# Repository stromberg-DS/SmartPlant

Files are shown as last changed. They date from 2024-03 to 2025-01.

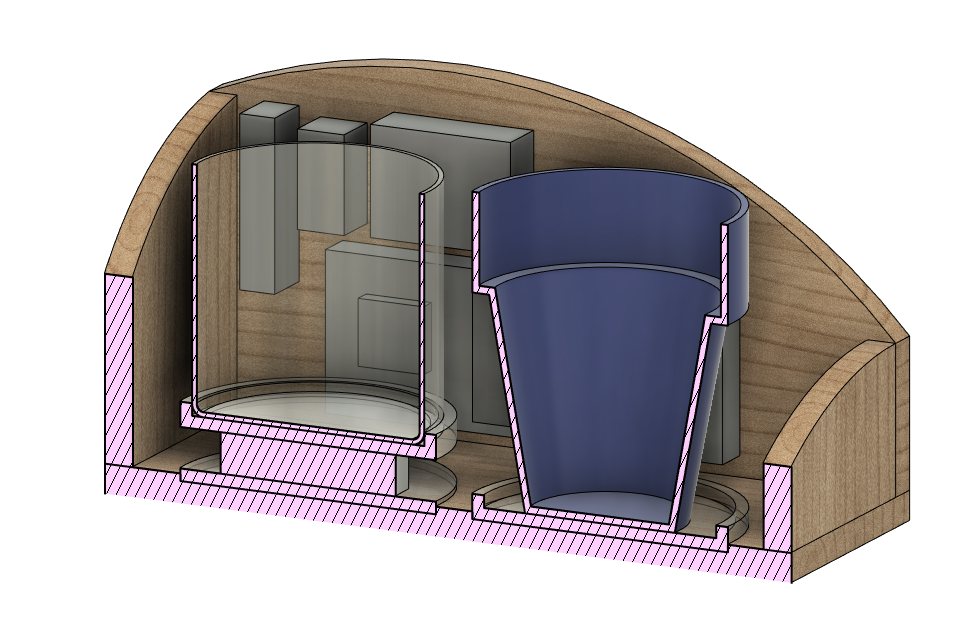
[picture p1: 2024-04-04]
Images/Slice.png

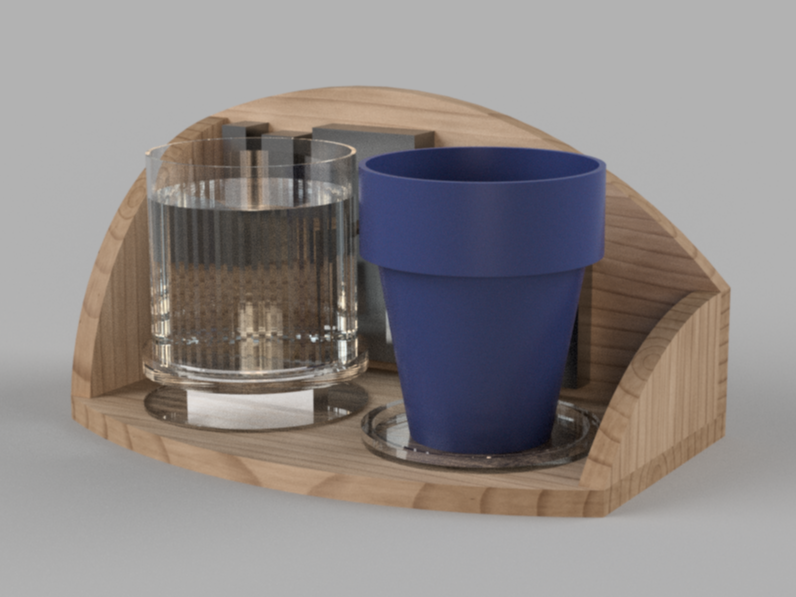
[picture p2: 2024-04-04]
Images/SmartPlant_Render1.png

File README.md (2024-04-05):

# SmartPlant

This is a smart plant system that monitors air quality, temperature, humidity, and more while keeping a plant watered and happy. All of the sensor data is displayed on an OLED in addition to publishing to an Adafruit.io dashboard.

The project runs on a Particle Photon 2 which was programmed in C++ in VS Code. Install the Particle Workbench to VS Code to edit any code here.

## Directory

**PlantCareAndMonitoringSystem** - This is the main project folder. The final code, wiring diagrams, and other important info is in this folder.

**Cut_Files** - Any files for laser cutting or cutting on a CNC router will be in here. 

**Images** - Pictures of my plant care and monitoring system.

**SP_#####Tests** - These were initial tests to dial in the sensors and code before combining them into the final product. Move along, nothing to see here.

More information and a list of parts can be found at [my Hackster.io writeup.](https://www.hackster.io/blotlat/plant-care-system-857033)

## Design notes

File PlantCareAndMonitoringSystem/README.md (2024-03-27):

# PlantCareAndMonitoringSystem

This firmware project was created using [Particle Developer Tools](https://www.particle.io/developer-tools/) and is compatible with all [Particle Devices](https://www.particle.io/devices/).

Feel free to replace this README.md file with your own content, or keep it for reference.

## Table of Contents
- [Introduction](#introduction)
- [Prerequisites To Use This Template](#prerequisites-to-use-this-repository)
- [Getting Started](#getting-started)
- [Particle Firmware At A Glance](#particle-firmware-at-a-glance)
  - [Logging](#logging)
  - [Setup and Loop](#setup-and-loop)
  - [Delays and Timing](#delays-and-timing)
  - [Testing and Debugging](#testing-and-debugging)
  - [GitHub Actions (CI/CD)](#github-actions-cicd)
  - [OTA](#ota)
- [Support and Feedback](#support-and-feedback)
- [Version](#version)

## Introduction

For an in-depth understanding of this project template, please refer to our [documentation](https://docs.particle.io/firmware/best-practices/firmware-template/).

## Prerequisites To Use This Repository

To use this software/firmware on a device, you'll need:

- A [Particle Device](https://www.particle.io/devices/).
- Windows/Mac/Linux for building the software and flashing it to a device.
- [Particle Development Tools](https://docs.particle.io/getting-started/developer-tools/developer-tools/) installed and set up on your computer.
- Optionally, a nice cup of tea (and perhaps a biscuit).

## Getting Started

1. While not essential, we recommend running the [device setup process](https://setup.particle.io/) on your Particle device first. This ensures your device's firmware is up-to-date and you have a solid baseline to start from.

2. If you haven't already, open this project in Visual Studio Code (File -> Open Folder). Then [compile and flash](https://docs.particle.io/getting-started/developer-tools/workbench/#cloud-build-and-flash) your device. Ensure your device's USB port is connected to your computer.

3. Verify the device's operation by monitoring its logging output:
    - In Visual Studio Code with the Particle Plugin, open the [command palette](https://docs.particle.io/getting-started/developer-tools/workbench/#particle-commands) and choose "Particle: Serial Monitor".
    - Or, using the Particle CLI, execute:
    ```
    particle serial monitor --follow
    ```

4. Uncomment the code at the bottom of the cpp file in your src directory to publish to the Particle Cloud! Login to console.particle.io to view your devices events in real time.

5. Customize this project! For firmware details, see [Particle firmware](https://docs.particle.io/reference/device-os/api/introduction/getting-started/). For information on the project's directory structure, visit [this link](https://docs.particle.io/firmware/best-practices/firmware-template/#project-overview).

## Particle Firmware At A Glance

### Logging

The firmware includes a [logging library](https://docs.particle.io/reference/device-os/api/logging/logger-class/). You can display messages at different levels and filter them:

```
Log.trace("This is trace message");
Log.info("This is info message");
Log.warn("This is warn message");
Log.error("This is error message");
```

### Setup and Loop

Particle projects originate from the Wiring/Processing framework, which is based on C++. Typically, one-time setup functions are placed in `setup()`, and the main application runs from the `loop()` function.

For advanced scenarios, explore our [threading support](https://docs.particle.io/firmware/software-design/threading-explainer/).

### Delays and Timing

By default, the setup() and loop() functions are blocking whilst they run, meaning that if you put in a delay, your entire application will wait for that delay to finish before anything else can run. 

For techniques that allow you to run multiple tasks in parallel without creating threads, checkout the code example [here](https://docs.particle.io/firmware/best-practices/firmware-template/).

(Note: Although using `delay()` isn't recommended for best practices, it's acceptable for testing.)

### Testing and Debugging

For firmware testing and debugging guidance, check [this documentation](https://docs.particle.io/troubleshooting/guides/build-tools-troubleshooting/debugging-firmware-builds/).

### GitHub Actions (CI/CD)

This project provides a YAML file for GitHub, automating firmware compilation whenever changes are pushed. More details on [Particle GitHub Actions](https://docs.particle.io/firmware/best-practices/github-actions/) are available.

### OTA

To learn how to utilize Particle's OTA service for device updates, consult [this documentation](https://docs.particle.io/getting-started/cloud/ota-updates/).

Test OTA with the 'Particle: Cloud Flash' command in Visual Studio Code or the CLI command 'particle flash'!

This firmware supports binary assets in OTA packages, allowing the inclusion of audio, images, configurations, and external microcontroller firmware. More details are [here](https://docs.particle.io/reference/device-os/api/asset-ota/asset-ota/).

## Support and Feedback

For support or feedback on this template or any Particle products, please join our [community](https://community.particle.io)!

## Version

Template version 1.0.2

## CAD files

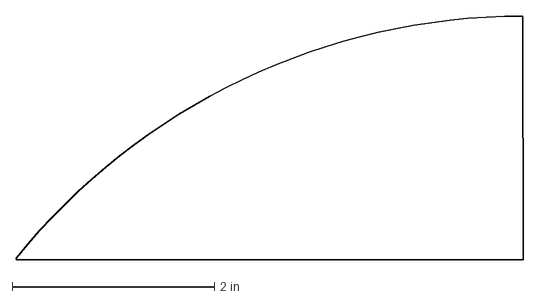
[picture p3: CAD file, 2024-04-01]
Cut_Files/RightWallCut.dxf
5.01 x 2.41 in

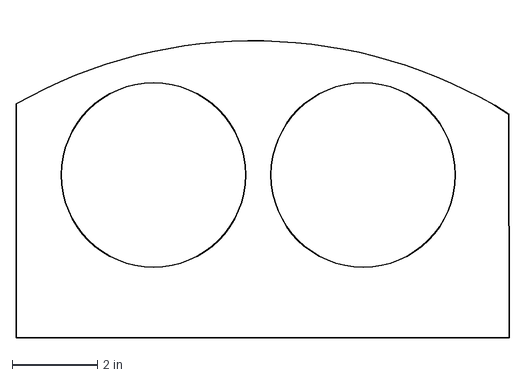
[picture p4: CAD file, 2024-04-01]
Cut_Files/ButtomCut.dxf
11.6 x 7.54 in

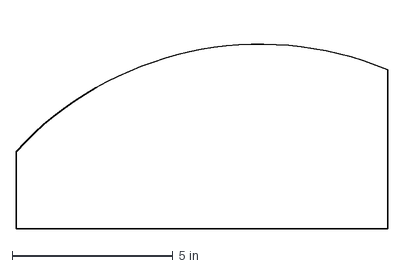
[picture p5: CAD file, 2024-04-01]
Cut_Files/BackWallCut.dxf
11.6 x 6.63 in

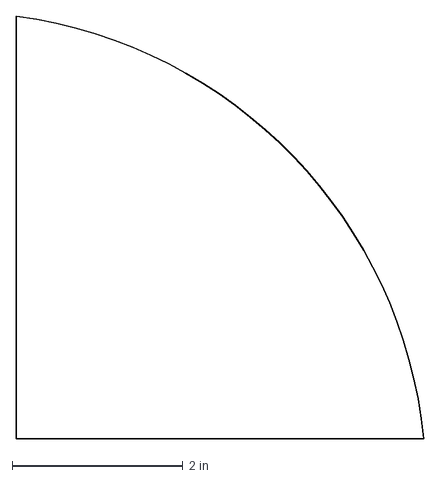
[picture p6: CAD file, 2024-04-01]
Cut_Files/LeftWallCut.dxf
4.77 x 4.95 in

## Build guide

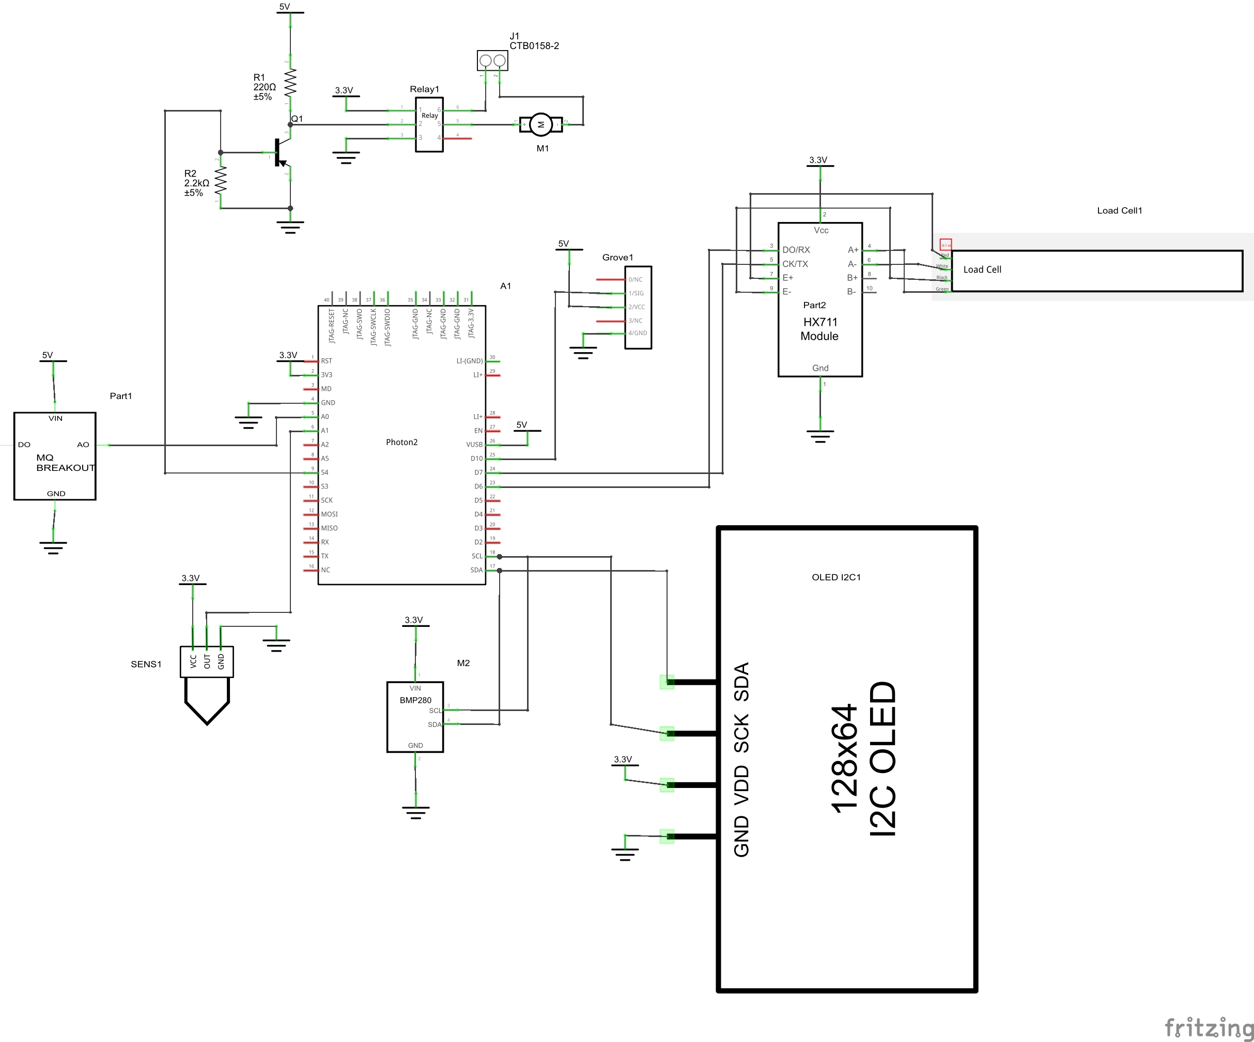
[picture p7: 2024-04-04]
PlantCareAndMonitoringSystem/SmartPlantWiring_schem.jpg

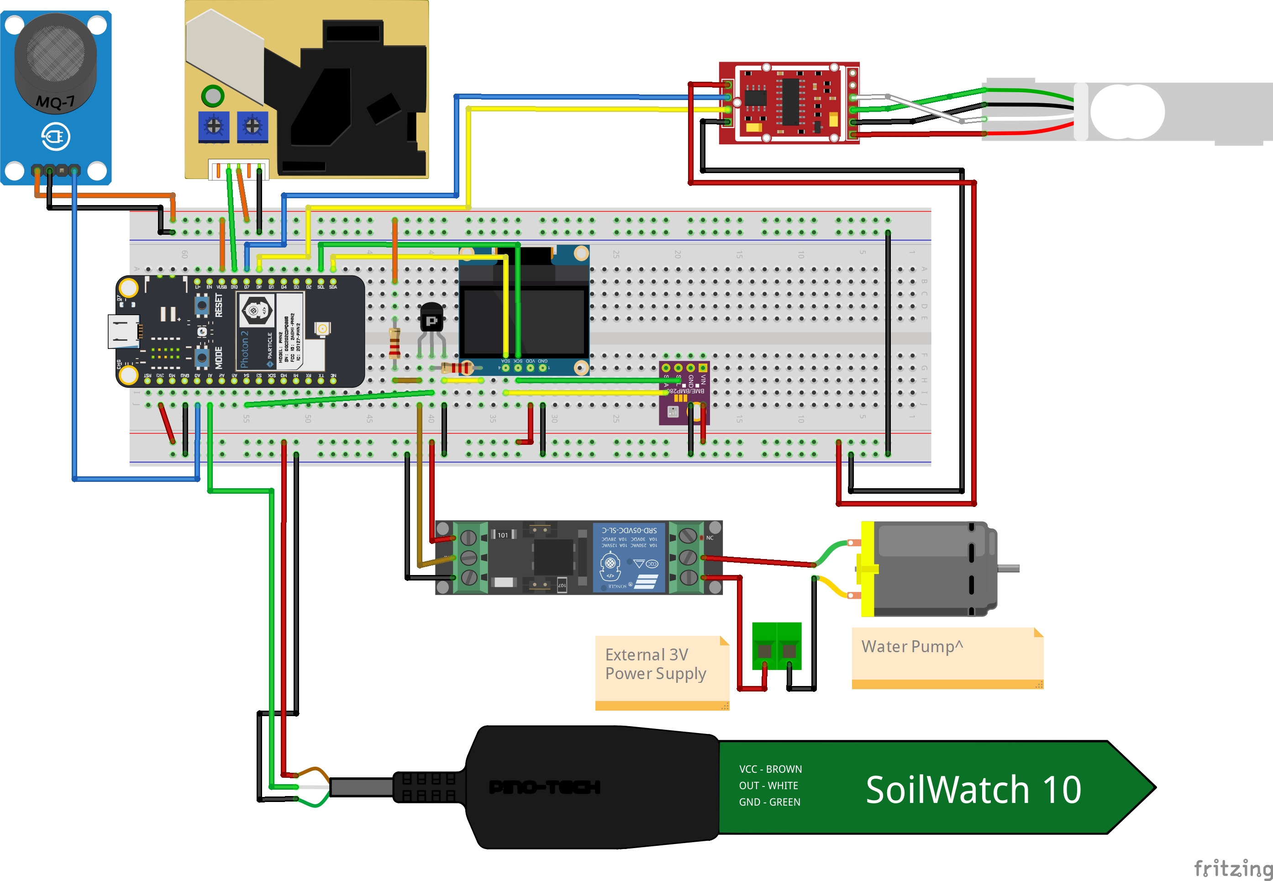
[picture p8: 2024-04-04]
PlantCareAndMonitoringSystem/SmartPlantWiring_bb.jpg

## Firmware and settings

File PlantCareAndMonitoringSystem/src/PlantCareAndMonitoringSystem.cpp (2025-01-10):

/* 
 * Plant Care & Monitoring System
 * Author: Daniel Stromberg
 * Date: 3/26/2024
*/

#include "Particle.h"
#include "math.h"
#include <Air_Quality_Sensor.h>
#include <Adafruit_MQTT/Adafruit_MQTT_SPARK.h>
#include <Adafruit_MQTT/Adafruit_MQTT.h>
#include "credentials.h"
#include <Adafruit_BME280.h>
#include <Adafruit_GFX.h>
#include <Adafruit_SSD1306.h>
#include "HX711.h"
#include "math.h"

//Sensor 
const int DUST_PIN = 10;
const int AIR_QUALITY_PIN = A0;
const int SAMPLE_TIME_MS = 30000;
const int BME_ADDRESS = 0x76;
const int SOIL_PIN = A1;

//Display 
const int OLED_RESET =-1;
const int OLED_ADDRESS = 0x3C;
const int DEGREE_SYMBOL = 0xF8;

//Pump 
const int PUMP_PIN = D19;
const int PUMP_ON_TIME = 500;
const int PUMP_TIMEOUT = 1800000;       //30 minutes
int lastPumpTime = -9999;
bool isPumpOn = false;
bool isWebButtonPressed;
bool isManualPumping = false;

//Moisture 
const int SENSOR_IN_WATER = 1744;       //when sensor is in pure pureWater
const int SENSOR_IN_AIR = 3485;         //sensor value in air
const int SENSOR_IN_WET_SOIL = 1770;    //sensor value in VERY wet soil
const int SENSOR_IN_DRY_SOIL = 3500;    //sensor value in dry soil
const int TIME_TO_WATER_PERCENT = 40;

//Scale 
const float CAL_FACTOR = -478.79;
const int SAMPLES = 10;
const float EMPTY_WEIGHT = 130.0;   //No water, pump and cup only
const float LOW_WEIGHT = 230.0;     //Lowest water level before pump stops working
const float FULL_WEIGHT = 625.0;    //Full of water. 

//Timing
int currentMillis;
int lastDisplayTime = 0;

//Dust/VOC Sensors
const int SAMPLE_TIME = 30000;
int duration;
int totalLowTime = 0;
int lowPulseOccupancy = 0;
int lastLowTime = 0;
int lastSampleTime;
float ratio = 0;
float concentration = 0;
String warningText;

//BME
bool status;


TCPClient TheClient;
Adafruit_MQTT_SPARK mqtt(&TheClient, AIO_SERVER, AIO_SERVERPORT, AIO_USERNAME, AIO_KEY);
Adafruit_MQTT_Publish dustPub = Adafruit_MQTT_Publish(&mqtt, AIO_USERNAME "/feeds/plantinfo.dustsensor");
Adafruit_MQTT_Publish airQualityText = Adafruit_MQTT_Publish(&mqtt, AIO_USERNAME "/feeds/airqualitywarningtext");
Adafruit_MQTT_Publish tempPub = Adafruit_MQTT_Publish(&mqtt, AIO_USERNAME "/feeds/temperature");
Adafruit_MQTT_Publish humidityPub = Adafruit_MQTT_Publish(&mqtt, AIO_USERNAME "/feeds/plantinfo.humidity");
Adafruit_MQTT_Publish scalePub = Adafruit_MQTT_Publish(&mqtt, AIO_USERNAME "/feeds/smartscale");
Adafruit_MQTT_Publish moisturePub = Adafruit_MQTT_Publish(&mqtt, AIO_USERNAME "/feeds/plantinfo.soilmoisture");
Adafruit_MQTT_Subscribe waterButtonFeed = Adafruit_MQTT_Subscribe(&mqtt, AIO_USERNAME "/feeds/buttononoff");

AirQualitySensor sensor(AIR_QUALITY_PIN);
Adafruit_SSD1306 display(OLED_RESET);
Adafruit_BME280 bme;
HX711 myScale(D6, D7);

String DateTime, TimeOnly, Day, MonthDate, Year;

SYSTEM_MODE(AUTOMATIC);
SYSTEM_THREAD(ENABLED);

//functions
void updateDisplays(String _airQuality, float _tempF, float _humidity, float _moisturePercent);
float tempCtoF(float c);
void MQTT_connect();
bool MQTT_ping();
void getConc();
float mapFloat(float inVal, float minIn, float maxIn, float minOut, float maxOut);


void setup() {
    Serial.begin(9600);
    waitFor(Serial.isConnected, 10000);
    new Thread("concThread", getConc); 

    pinMode(PUMP_PIN, OUTPUT);
    digitalWrite(PUMP_PIN, LOW);
    pinMode(SOIL_PIN, INPUT);

    Time.zone(-7);
    Time.beginDST();
    Particle.syncTime();

    status = bme.begin(BME_ADDRESS);
    if (status == false){
      Serial.printf("BME Failed to start at address 0x%02X", BME_ADDRESS);
    }

    display.begin(SSD1306_SWITCHCAPVCC, OLED_ADDRESS);
    display.clearDisplay();
    display.setTextColor(WHITE);
    display.setTextSize(1);
    display.display();

    myScale.set_scale();
    delay(5000);        //let scale settle
    myScale.tare();
    myScale.set_scale(CAL_FACTOR);

    mqtt.subscribe(&waterButtonFeed);

    pinMode(DUST_PIN, INPUT);
    lastSampleTime = millis();
    
}

void loop() {
    currentMillis = millis();
    float weight;
    int quality;
    float waterPercent;
    float tempC;
    float tempF;
    float humidity;
    int moistureLevel = analogRead(SOIL_PIN);
    int moisturePercent;
    int timeSinceLastPump = currentMillis - lastPumpTime;

    DateTime = Time.timeStr();
    MonthDate = DateTime.substring(4, 10);
    TimeOnly =  DateTime.substring(11, 19);
    Day = DateTime.substring(0,3);

    //update Sensors/display
    moisturePercent = constrain(map(moistureLevel, SENSOR_IN_DRY_SOIL, SENSOR_IN_WET_SOIL, 0, 100),0,100);
    quality = sensor.slope();
    weight = constrain(myScale.get_units(SAMPLES), 0, 5000);
    waterPercent = constrain(mapFloat(weight, LOW_WEIGHT, FULL_WEIGHT, 0, 100), 0, 110);
    tempF = tempCtoF(bme.readTemperature());
    humidity = bme.readHumidity();
    if(millis() - lastDisplayTime > 3000){
        updateDisplays(warningText, tempF, humidity, moisturePercent);
        Serial.printf("Moisture: %i\n", moistureLevel);
        Serial.printf("Moist Percent: %i\n", moisturePercent);
        lastDisplayTime = millis();
    }   


    Adafruit_MQTT_Subscribe *subscription;
    while ((subscription = mqtt.readSubscription(100))){
        if(subscription == &waterButtonFeed){
            //atof: ascii to float
            //char * turns binary into characters
            isWebButtonPressed = bool(atof((char *)waterButtonFeed.lastread));
        }
    }


    if(millis()-lastSampleTime > SAMPLE_TIME_MS){
        Serial.printf("Dust Concentration: %0.2f\n", concentration);
        lastSampleTime = millis();

        if(quality == 0){
            warningText = "Extreme VOCs!";
        }else if(quality == 1){
            warningText = "High VOCs.";
        } else if (quality == 2){
            warningText = "Low VOCs";
        } else if(quality == 3){
            warningText = "Fresh Air!";
        }

        if(mqtt.Update()){
            scalePub.publish(waterPercent); 
            dustPub.publish(concentration);
            moisturePub.publish(moisturePercent);
            tempPub.publish(tempF);
            humidityPub.publish(humidity);
            airQualityText.publish(warningText);
            Serial.printf("Water Percent: %f\n", waterPercent);
            Serial.printf("Moist Percent: %i\n\n", moisturePercent);
        }
    }
  
    if(timeSinceLastPump > PUMP_ON_TIME){
        digitalWrite(PUMP_PIN, LOW);
    }

    if((moisturePercent<TIME_TO_WATER_PERCENT && timeSinceLastPump > PUMP_TIMEOUT) || isWebButtonPressed){
        digitalWrite(PUMP_PIN, HIGH);
        lastPumpTime = currentMillis;
    }

    MQTT_connect();
    MQTT_ping();

}

//Convert sensor temperature from celcius to Fahrenheit
float tempCtoF(float c){
    return ((c*9/5)+32);
}

float mapFloat(float inVal, float minIn, float maxIn, float minOut, float maxOut){
    return (inVal-minIn)*(maxOut-minOut)/(maxIn-minIn) + minOut;
}

//Update all local displays at once
void updateDisplays(String _airQuality, float _tempF, float _humidity, float _moisturePercent){
    // Serial.printf("Temperature: %0.1fF\n\n", tempF);
    display.clearDisplay();
    display.setCursor(0,0);
    display.setTextSize(2);
    display.printf("%0.0f%cF %0.0f%%\n", _tempF, DEGREE_SYMBOL, _humidity);
    display.setTextSize(1);
    display.printf("\nSoil: %0.0f%%\n", _moisturePercent);
    display.printf("Dust: %0.0f\n%s\n\n", concentration, _airQuality.c_str());
    display.printf("%s, %s %s\n", Day.c_str(), MonthDate.c_str(), TimeOnly.c_str());
    display.display();
}


// Function to connect and reconnect as necessary to the MQTT server.
// Should be called in the loop function and it will take care if connecting.
void MQTT_connect() {
    int8_t ret;

    // Return if already connected.
    if (mqtt.connected()) {
    return;
    }

    Serial.print("Connecting to MQTT... ");

    while ((ret = mqtt.connect()) != 0) { // connect will return 0 for connected
        Serial.printf("Error Code %s\n",mqtt.connectErrorString(ret));
        Serial.printf("Retrying MQTT connection in 5 seconds...\n");
        mqtt.disconnect();
        delay(5000);  // wait 5 seconds and try again
    }
    Serial.printf("MQTT Connected!\n");
}

//Keeps the connection open to Adafruit
bool MQTT_ping() {
    static unsigned int last;
    bool pingStatus;

    if ((millis()-last)>120000) {
        Serial.printf("Pinging MQTT \n");
        pingStatus = mqtt.ping();
        if(!pingStatus) {
        Serial.printf("Disconnecting \n");
        mqtt.disconnect();
        }
        last = millis();
    }
    return pingStatus;
}

void getConc(){
    unsigned int duration, startTime;
    startTime = 0;
    lowPulseOccupancy =0;

    while (true)
    {
        duration = pulseIn(DUST_PIN, LOW);
        lowPulseOccupancy = lowPulseOccupancy + duration;
        if ((millis()-startTime)>SAMPLE_TIME){
            if(totalLowTime == 0){
                totalLowTime = lastLowTime;
            } else{
                lastLowTime = totalLowTime;
            }

            ratio = lowPulseOccupancy/(SAMPLE_TIME*10.0);
            concentration = 1.1*pow(ratio,3)-3.8*pow(ratio,2)+520*ratio +0.62;
            startTime = millis();
            lowPulseOccupancy=0;
        }
    }
    
}


//Put Photon2 to sleep for 30 minutes
void sleep(){
    SystemSleepConfiguration config;
    config.mode(SystemSleepMode::STOP).gpio(WKP, RISING).duration(30min);
    System.sleep(config);
}

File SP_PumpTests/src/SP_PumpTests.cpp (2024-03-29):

/* 
 * Pump/Relay Tests
 * Author: Daniel Stromberg
 * Date: 3/25/2024
*/

#include "Particle.h"
#include <Button.h>

const int BUTTON_PIN = D2;
const int PUMP_PIN = D19;
const int PUMP_ON_TIME = 500;
const int SOIL_PIN = A1;
const int sensorInWater = 1744;     //when sensor is in pure pureWater
const int sensorInAir = 3485;       //sensor value in air
const int sensorInWetSoil = 1770;   //sensor value in VERY wet sensor
const int sensorInDrySoil = 3000;   //sensor value in dry soil
const int MIN_WATERING_INTERVAL = 5000;    //Minimum time between watering.

int currentMillis;
int lastMillis = -9999;


SYSTEM_MODE(MANUAL);
SYSTEM_THREAD(ENABLED);

Button moistureButton(BUTTON_PIN, true);

void setup() {
    Serial.begin(9600);
    pinMode(PUMP_PIN, OUTPUT);
    pinMode(SOIL_PIN, INPUT);
}

void loop() {
    currentMillis = millis();
    int moistureLevel = analogRead(SOIL_PIN);
    int timeSinceLastPump = currentMillis - lastMillis;

    if(currentMillis %1000 == 0){
        Serial.printf("Moisture Level: %i\n", moistureLevel);
        Serial.printf("TimeSincePump: %i\n\n", timeSinceLastPump);
    }

    if(timeSinceLastPump > PUMP_ON_TIME){
        digitalWrite(PUMP_PIN, LOW);

    }

    if(moistureLevel >3000 && timeSinceLastPump > MIN_WATERING_INTERVAL){
        digitalWrite(PUMP_PIN, HIGH);
        lastMillis = currentMillis;
    }


}

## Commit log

2024-03-17 Created base sensor test file
2024-03-21 Dust, VOC sensor working. OLED, BME working
    [SmartPlant.fzz]
2024-03-25 Added pump and relay wiring diagram
    [PumpTest.fzz]
2024-03-26 Relay and pump working with button press
2024-03-26 Pump triggered by moisture sensor. Lond delay between watering.
2024-03-27 Combined sensor and pump code
    [PumpTest.fzz, SP_SensorTests.fzz, SmartPlantWiring.fzz]
2024-03-29 Added threading and things seem to work ok
2024-04-01 Added scale test
    [BackWallCut.dxf, ButtomCut.dxf, LeftWallCut.dxf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]
2024-04-04 Trying to iron out dust sensor threading
2024-04-04 Updated wiring, added photos
    [SmartPlantWiring.fzz]
2024-04-04 Added humidity and temperature publishing
2024-04-20 Fixed dust sensor threading, adjusted soil moisture output
    [PlantCareAndMonitoringSystem.cpp, SP_SensorTests.cpp]
2025-01-10 Checks water before pumping. Sets LED if water is low.
2025-01-10 Added unused sleep function. Lowered sampling rate of sensors.
2025-01-10 Revert "Checks water before pumping. Sets LED if water is low."
    This reverts commit bb26842917c7f3ff08184c6d25663d5686618e01.
    [PlantCareAndMonitoringSystem.cpp]
2025-01-10 Revert "Added unused sleep function. Lowered sampling rate of sensors."
    This reverts commit 623ca2d7e2490a92241096bf001437a31094a88d.
    [PlantCareAndMonitoringSystem.cpp]
